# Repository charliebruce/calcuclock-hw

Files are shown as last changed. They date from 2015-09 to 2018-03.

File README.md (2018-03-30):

# calcuclock-hw
PCB and schematic for the calcuclock project. The firmware for this hardware can be found at https://github.com/charliebruce/calcuclock-sw

This PCB can be purchased through OSHPark: https://oshpark.com/shared_projects/vCfoimMo

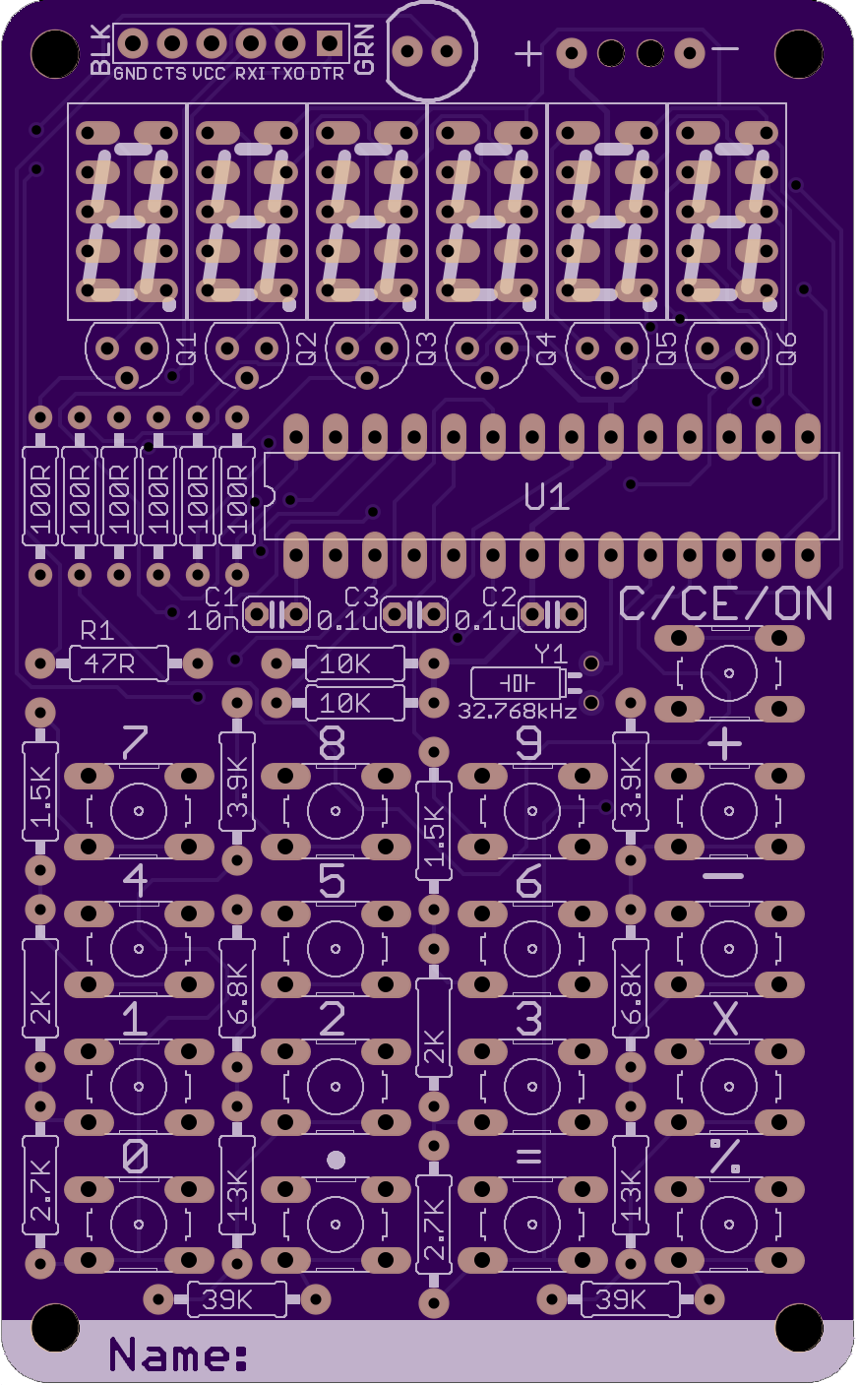
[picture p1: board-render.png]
PCB Render


# License
Released under the CC BY-NC-SA 3.0 license.

For more details see a summary at:
https://creativecommons.org/licenses/by-nc-sa/3.0/ 
and the accompanying legal text:
https://creativecommons.org/licenses/by-nc-sa/3.0/legalcode

Please raise an issue or send me an email if you wish to use this project commercially.

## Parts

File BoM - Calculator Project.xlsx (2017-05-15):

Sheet: Parts
Calculator Project - BOM
Quantity required | 12 |  | VAT Rate | 20.0%
Item | Qty required/kit | OC (Farnell) | Qty required total | Qty (MOQ) | Price/unit | Line Total |  | MOQ | 1 | 5 | 10 | 25 | 50 | 100 | 250 | 500 | 1000 | 3000 | 5000
7-Segment CA (Green) | 6 | 1830007 | 72 | 72 | £0.31 | £22.32 |  | 1 | £0.33 | £0.33 | £0.33 | £0.31 | £0.31 | £0.27 | £0.26 | £0.24 | £0.24 | £0.24 | £0.24
 |  | Colour Options: 1830007 , 1830002 , 1830009 , 1830005 , 1830011.
ATmega328P-PU | 1 | 1715487 | 12 | 12 | £1.64 | £19.68 |  | 1 | £2.81 | £2.81 | £1.64 | £1.64 | £1.64 | £1.34 | £1.33 | £1.33 | £1.33 | £1.33 | £1.33
Switch, SPST | 17 | 9471685 | 204 | 205 | £0.04 | £9.02 |  | 5 |  | £0.09 | £0.09 | £0.09 | £0.08 | £0.04 | £0.04 | £0.04 | £0.04 | £0.04 | £0.04
Capacitor, 10nF | 1 | 1216425 | 12 | 15 | £0.07 | £1.01 |  | 5 |  | £0.07 | £0.07 | £0.07 | £0.06 | £0.04 | £0.04 | £0.03 | £0.03 | £0.03 | £0.03
Capacitor, 0.1uF | 2 | 2309020 | 24 | 24 | £0.02 | £0.55 |  | 1 | £0.03 | £0.03 | £0.02 | £0.02 | £0.02 | £0.02 | £0.02 | £0.02 | £0.01 | £0.01 | £0.01
Crystal, 32.768khz | 1 | 1652573 | 12 | 12 | £0.11 | £1.34 |  | 1 | £0.11 | £0.11 | £0.11 | £0.10 | £0.09 | £0.08 | £0.08 | £0.07 | £0.07 | £0.07 | £0.07
Transistor, PNP | 6 | 1574374 | 72 | 75 | £0.11 | £8.25 |  | 5 |  | £0.14 | £0.14 | £0.11 | £0.11 | £0.07 | £0.07 | £0.07 | £0.04 | £0.04 | £0.04
Header, 6 pin, RA | 1 | 1593430 | 12 | 20 | £0.19 | £3.82 |  | 10 |  |  | £0.19 | £0.19 | £0.13 | £0.08 | £0.08 | £0.06 | £0.05 | £0.05 | £0.05
Battery Container | 1 | Rapid: 18-0124 | 12 | 12 | £0.26 | £3.08 |  | 1 | £0.26 | £0.26 | £0.26 | £0.20 | £0.20 | £0.15 | £0.15 | £0.13 | £0.13 | £0.13 | £0.13
IR TX | 1 | 2290441 | 12 | 12 | £0.08 | £0.97 |  | 1 | £0.09 | £0.09 | £0.08 | £0.08 | £0.08 | £0.07 | £0.07 | £0.06 | £0.06 | £0.06 | £0.06
IR RX?
IR Trans?
Chip socket?
Resistors
100R 5% | 6 | 2329473 | 72 | 80 | £0.01 | £0.88 |  | 10 |  |  | £0.01 | £0.01 | £0.01 | £0.01 | £0.01 | £0.01 | £0.01 | £0.01 | £0.01
47R 5% | 1 | 2329533 | 12 | 20 | £0.01 | £0.26 |  | 10 |  |  | £0.01 | £0.01 | £0.01 | £0.01 | £0.01 | £0.01 | £0.01 | £0.01 | £0.01
10K | 2 | 2329474 | 24 | 30 | £0.01 | £0.39 |  | 10 |  |  | £0.01 | £0.01 | £0.01 | £0.01 | £0.01 | £0.01 | £0.01 | £0.01 | £0.01
1.5K | 2 | 9341323 | 24 | 50 | £0.06 | £2.75 |  | 50 |  |  |  |  | £0.06 | £0.06 | £0.06 | £0.05 | £0.03 | £0.03 | £0.02
2K | 2 | 9341480 | 24 | 50 | £0.03 | £1.35 |  | 50 |  |  |  |  | £0.03 | £0.03 | £0.03 | £0.02 | £0.02 | £0.02 | £0.01
2.7K | 2 | 9341641 | 24 | 50 | £0.06 | £2.75 |  | 50 |  |  |  |  | £0.06 | £0.06 | £0.06 | £0.05 | £0.03 | £0.03 | £0.02
3.9K | 2 | 9341854 | 24 | 50 | £0.06 | £2.75 |  | 50 |  |  |  |  | £0.06 | £0.06 | £0.06 | £0.05 | £0.03 | £0.03 | £0.02
6.8K | 2 | 9342168 | 24 | 50 | £0.06 | £2.75 |  | 50 |  |  |  |  | £0.06 | £0.06 | £0.06 | £0.05 | £0.03 | £0.03 | £0.02
13K | 2 | 9341285 | 24 | 50 | £0.03 | £1.30 |  | 50 |  |  |  |  | £0.03 | £0.03 | £0.03 | £0.02 | £0.02 | £0.02 | £0.01
39K | 2 | 2329932 | 24 | 30 | £0.02 | £0.63 |  | 10 |  |  | £0.02 | £0.02 | £0.02 | £0.01 | £0.01 | £0.01 | £0.01 | £0.01 | £0.01
PCB (90x55mm, dual layer) | 1 |  | 12 | 12 | £1.90 | £22.80 |  | 12
 |  |  |  |  | VAT | £21.73
 |  |  |  |  | Total | £130.39 | (as listed - quote may lower price)
 |  |  |  |  |  | £10.87 | per unit

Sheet: Alt PCB.
Alt PCB services
PCBCart | ENIG | 12day |  |  |  |  | 55.926 | tool
$2.04 | £1.33 |  |  | 50 | £66.30 |  | £122.23 |  | £2.44 | each, qty | 50 | exc ship, qc fail, import
$1.55 | £1.01 |  | for | 100 | £100.75 | exc tooling | £156.68 |  | £1.57 | each, qty | 100
$1.29 | £0.84 |  |  | 200 | £167.70 |  | £223.63 |  | £1.12 | each, qty | 200
$1.22 | £0.79 |  |  | 250 | £198.25 |  | £254.18 |  | £1.02 | each, qty | 250
$0.99 | £0.64 |  |  | 500 | £321.75 |  | £377.68 |  | £0.76 | each, qty | 500
$0.87 | £0.57 |  |  | 1000 | £565.50 |  | £621.43 |  | £0.62 | each, qty | 1000
$0.78 | £0.51 |  |  | 2000 | £1014.00 |  | £1069.93 |  | £0.53 | each, qty | 2000

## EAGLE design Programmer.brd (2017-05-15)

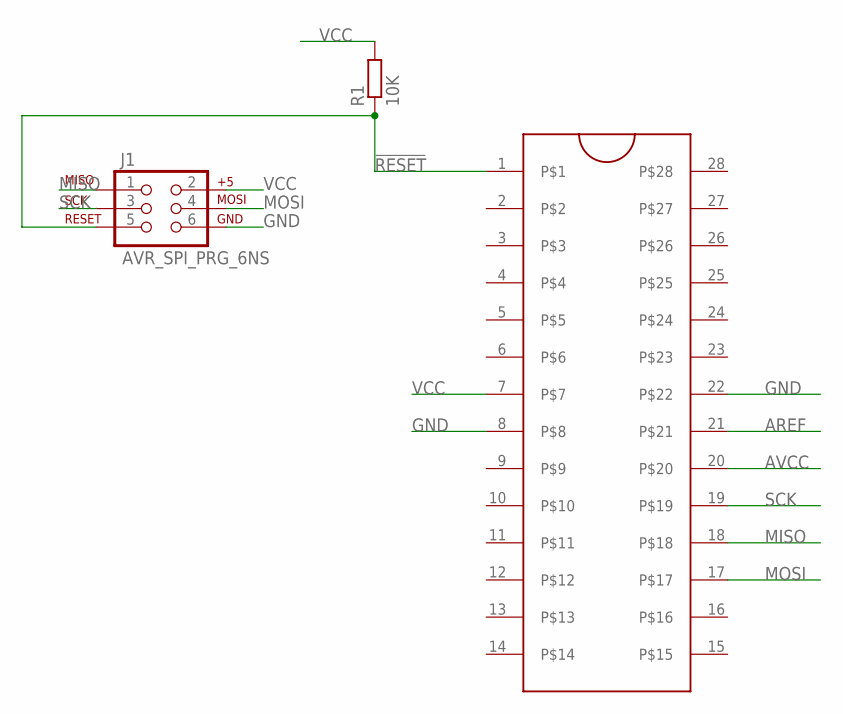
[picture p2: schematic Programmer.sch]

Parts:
J1: AVR_SPI_PRG_6NS; 2X3-NS
R1: 10K; 0207/10
U$1: ZIFSOCKET-28-3ZIFFSOCKET-28-3; DIL28-3-ZIF_SOCKET

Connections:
!RESET!: J1.5, R1.1, U$1.1
AREF: U$1.21
AVCC: U$1.20
GND: J1.6, U$1.8, U$1.22
MISO: J1.1, U$1.18
MOSI: J1.4, U$1.17
SCK: J1.3, U$1.19
VCC: J1.2, R1.2, U$1.7

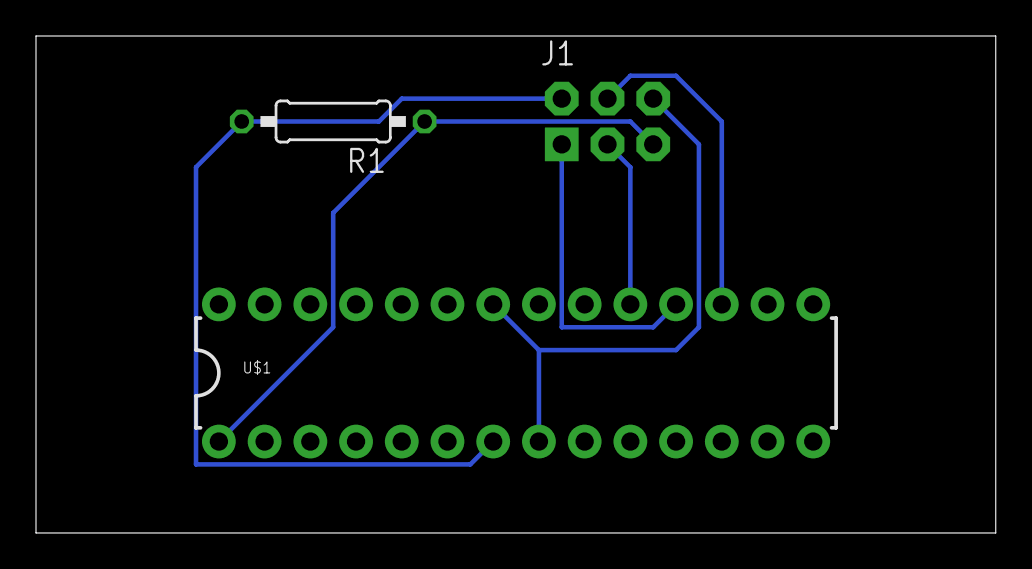
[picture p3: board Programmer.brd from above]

Board: 2 copper layers, 53.3 x 27.6 mm, 3 parts (0 on the bottom side), 6 nets.

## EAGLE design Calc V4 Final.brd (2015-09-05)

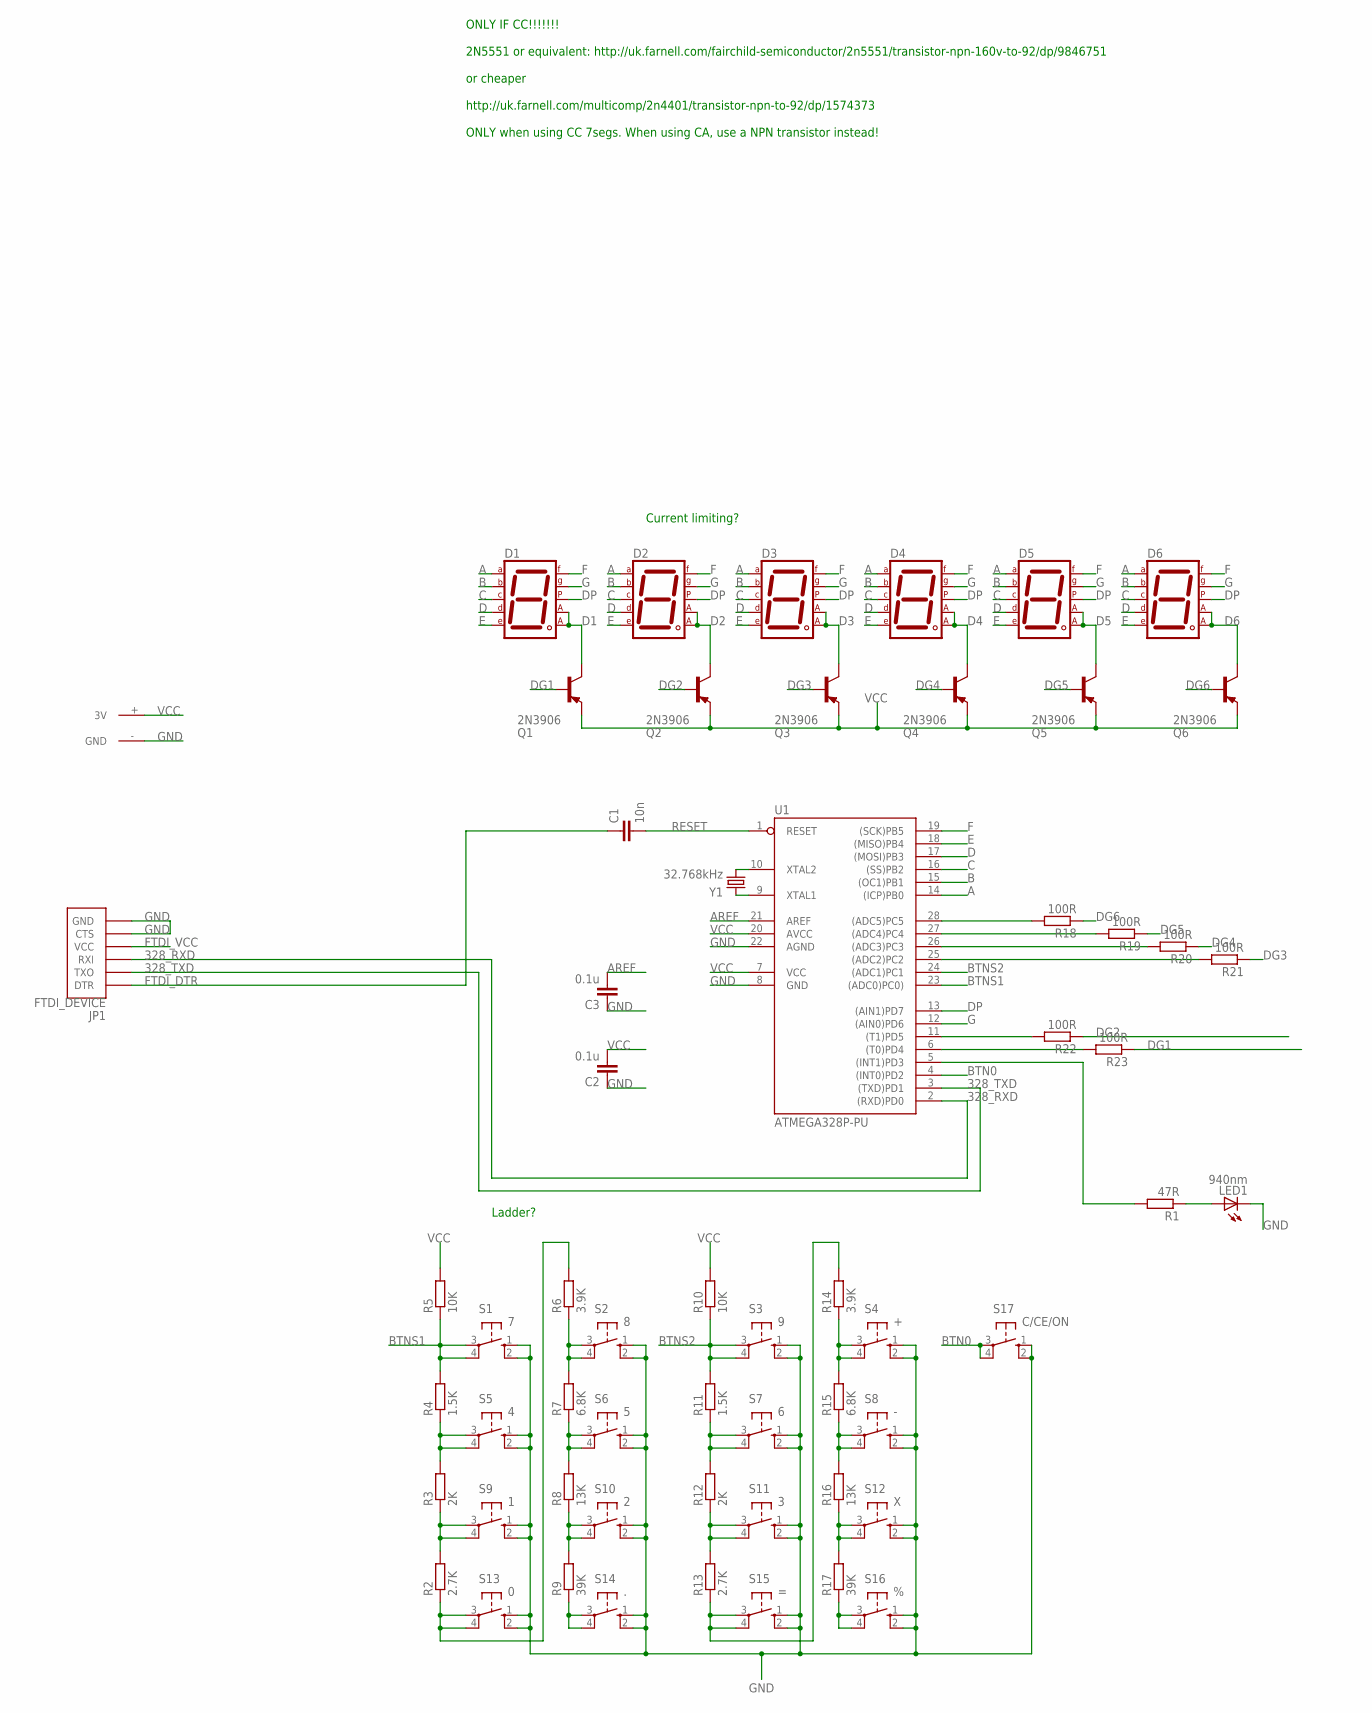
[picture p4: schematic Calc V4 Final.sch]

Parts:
C1: 10n; C025-024X044
C2, C3: 0.1u; C025-024X044
D1, D2, D3, D4, D5, D6: 7SEG-MCA; 7SEG-7
JP1: FTDI_DEVICE; FTDI_DEVICE_SIDE
LED1: 940nm; LED5MM
Q1, Q2, Q3, Q4, Q5, Q6: 2N3906; TO92
R1: 47R; 0207/10
R2, R13: 2.7K; 0207/10
R3, R12: 2K; 0207/10
R4, R11: 1.5K; 0207/10
R5, R10: 10K; 0207/10
R6, R14: 3.9K; 0207/10
R7, R15: 6.8K; 0207/10
R8, R16: 13K; 0207/10
R9, R17: 39K; 0207/10
R18, R19, R20, R21, R22, R23: 100R; 0207/7
S1: 7; B3F-10XX
S2: 8; B3F-10XX; MPN B3F-1000
S3: 9; B3F-10XX; MPN B3F-1000
S4: +; B3F-10XX; MPN B3F-1000
S5: 4; B3F-10XX; MPN B3F-1000
S6: 5; B3F-10XX; MPN B3F-1000
S7: 6; B3F-10XX; MPN B3F-1000
S8: -; B3F-10XX; MPN B3F-1000
S9: 1; B3F-10XX
S10: 2; B3F-10XX; MPN B3F-1000
S11: 3; B3F-10XX; MPN B3F-1000
S12: X; B3F-10XX; MPN B3F-1000
S13: 0; B3F-10XX; MPN B3F-1000
S14: .; B3F-10XX; MPN B3F-1000
S15: =; B3F-10XX; MPN B3F-1000
S16: %; B3F-10XX; MPN B3F-1000
S17: C/CE/ON; B3F-10XX; MPN B3F-1000
U1: ATMEGA328P-PU; DIL28-3
U$1: AAA-BATTERY; AAA-BATTERY-CONTACT
Y1: 32.768kHz; TC26HEZ

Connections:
328_RXD: JP1.P$3 (RXI), U1.2 ((RXD)PD0)
328_TXD: JP1.P$2 (TXO), U1.3 ((TXD)PD1)
A: D1.10 (A), D2.10 (A), D3.10 (A), D4.10 (A), D5.10 (A), D6.10 (A), U1.14 ((ICP)PB0)
AREF: C3.2, U1.21 (AREF)
B: D1.9 (B), D2.9 (B), D3.9 (B), D4.9 (B), D5.9 (B), D6.9 (B), U1.15 ((OC1)PB1)
BTN0: S17.3, S17.4 (P1), U1.4 ((INT0)PD2)
BTNS1: R4.2, R5.1, S1.3, S1.4 (P1), U1.23 ((ADC0)PC0))
BTNS2: R10.1, R11.2, S3.3, S3.4 (P1), U1.24 ((ADC1)PC1)
C: D1.8 (C), D2.8 (C), D3.8 (C), D4.8 (C), D5.8 (C), D6.8 (C), U1.16 ((SS)PB2)
D: D1.5 (D), D2.5 (D), D3.5 (D), D4.5 (D), D5.5 (D), D6.5 (D), U1.17 ((MOSI)PB3)
D1: D1.1 (CA1), D1.6 (CA2), Q1.1 (C)
D2: D2.1 (CA1), D2.6 (CA2), Q2.1 (C)
D3: D3.1 (CA1), D3.6 (CA2), Q3.1 (C)
D4: D4.1 (CA1), D4.6 (CA2), Q4.1 (C)
D5: D5.1 (CA1), D5.6 (CA2), Q5.1 (C)
D6: D6.1 (CA1), D6.6 (CA2), Q6.1 (C)
DG1: Q1.2 (B), R23.1
DG2: Q2.2 (B), R22.1
DG3: Q3.2 (B), R21.1
DG4: Q4.2 (B), R20.1
DG5: Q5.2 (B), R19.1
DG6: Q6.2 (B), R18.1
DP: D1.7 (DP), D2.7 (DP), D3.7 (DP), D4.7 (DP), D5.7 (DP), D6.7 (DP), U1.13 ((AIN1)PD7)
E: D1.4 (E), D2.4 (E), D3.4 (E), D4.4 (E), D5.4 (E), D6.4 (E), U1.18 ((MISO)PB4)
F: D1.2 (F), D2.2 (F), D3.2 (F), D4.2 (F), D5.2 (F), D6.2 (F), U1.19 ((SCK)PB5)
FTDI_DTR: C1.1, JP1.P$1 (DTR)
FTDI_VCC: JP1.P$4 (VCC)
G: D1.3 (G), D2.3 (G), D3.3 (G), D4.3 (G), D5.3 (G), D6.3 (G), U1.12 ((AIN0)PD6)
GND: C2.1, C3.1, JP1.P$5 (CTS), JP1.P$6 (GND), LED1.K (C), S1.1 (S), S1.2 (S1), S2.1 (S), S2.2 (S1), S3.1 (S), S3.2 (S1), S4.1 (S), S4.2 (S1), S5.1 (S), S5.2 (S1), S6.1 (S), S6.2 (S1), S7.1 (S), S7.2 (S1), S8.1 (S), S8.2 (S1), S9.1 (S), S9.2 (S1), S10.1 (S), S10.2 (S1), S11.1 (S), S11.2 (S1), S12.1 (S), S12.2 (S1), S13.1 (S), S13.2 (S1), S14.1 (S), S14.2 (S1), S15.1 (S), S15.2 (S1), S16.1 (S), S16.2 (S1), S17.1 (S), S17.2 (S1), U1.8 (GND), U1.22 (AGND), U$1.- (GND)
unnamed: LED1.A, R1.1
unnamed: R1.2, U1.5 ((INT1)PD3)
unnamed: R2.1, R6.2, S13.3, S13.4 (P1)
unnamed: R2.2, R3.1, S9.3, S9.4 (P1)
unnamed: R3.2, R4.1, S5.3, S5.4 (P1)
unnamed: R6.1, R7.2, S2.3, S2.4 (P1)
unnamed: R9.1, S14.3, S14.4 (P1)
unnamed: R8.1, R9.2, S10.3, S10.4 (P1)
unnamed: R7.1, R8.2, S6.3, S6.4 (P1)
unnamed: R18.2, U1.28 ((ADC5)PC5)
unnamed: R11.1, R12.2, S7.3, S7.4 (P1)
unnamed: R13.1, R14.2, S15.3, S15.4 (P1)
unnamed: R12.1, R13.2, S11.3, S11.4 (P1)
unnamed: R17.1, S16.3, S16.4 (P1)
unnamed: R16.1, R17.2, S12.3, S12.4 (P1)
unnamed: R15.1, R16.2, S8.3, S8.4 (P1)
unnamed: R14.1, R15.2, S4.3, S4.4 (P1)
unnamed: R19.2, U1.27 ((ADC4)PC4)
unnamed: R20.2, U1.26 ((ADC3)PC3)
unnamed: R21.2, U1.25 ((ADC2)PC2)
unnamed: R22.2, U1.11 ((T1)PD5)
unnamed: R23.2, U1.6 ((T0)PD4)
RESET: C1.2, U1.1 (RESET)
VCC: C2.2, Q1.3 (E), Q2.3 (E), Q3.3 (E), Q4.3 (E), Q5.3 (E), Q6.3 (E), R5.2, R10.2, U1.7 (VCC), U1.20 (AVCC), U$1.+ (3V)
XTAL_N: U1.9 (XTAL1), Y1.2
XTAL_P: U1.10 (XTAL2), Y1.1

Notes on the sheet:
Ladder?
Current limiting?
ONLY IF CC!!!!!!! 2N5551 or equivalent: http://uk.farnell.com/fairchild-semiconductor/2n5551/transistor-npn-160v-to-92/dp/9846751 or cheaper http://uk.farnell.com/multicomp/2n4401/transistor-npn-to-92/dp/1574373 ONLY when using CC 7segs. When using CA, use a NPN transistor instead!

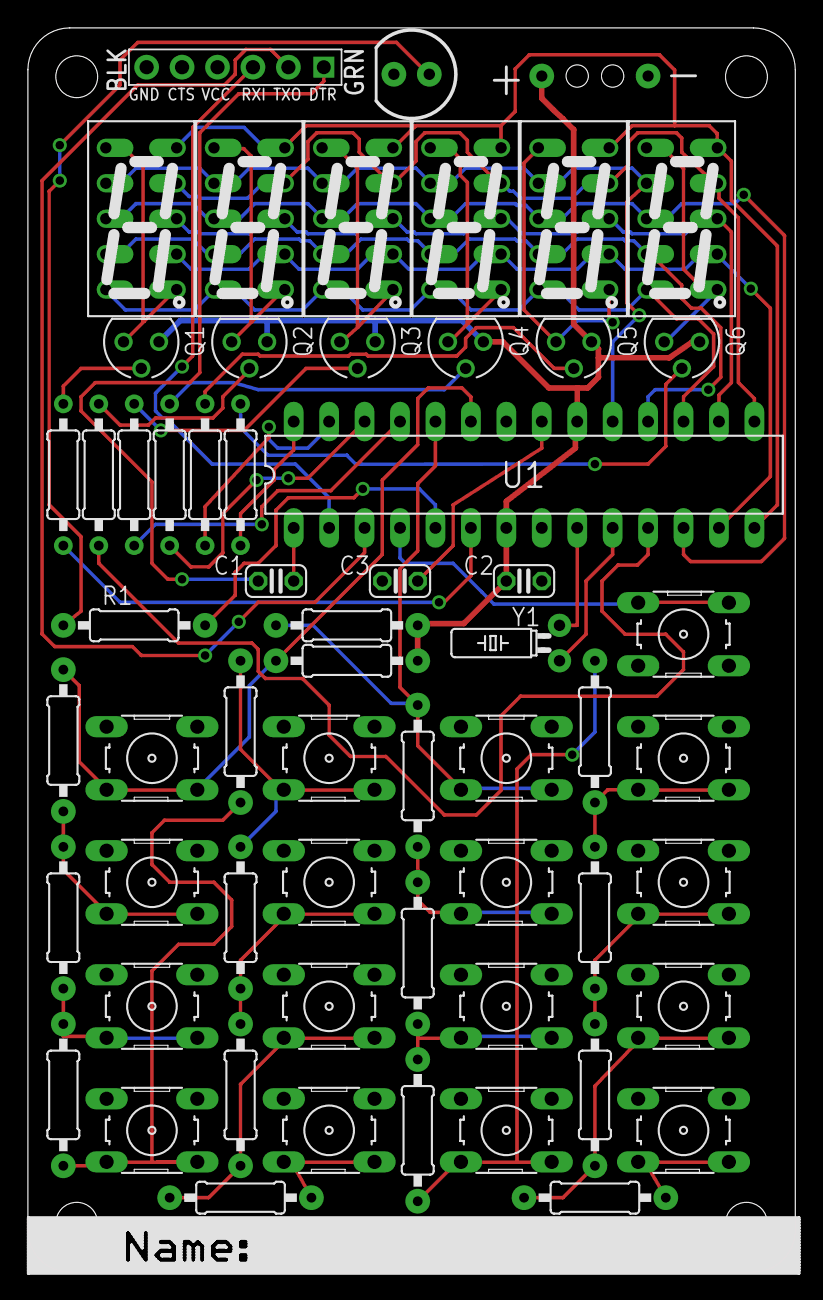
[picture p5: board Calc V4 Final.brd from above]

Board: 2 copper layers, 55.0 x 89.2 mm, 60 parts (0 on the bottom side), 54 nets.

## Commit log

2015-09-05 Initial commit of calcuclock PCB design.
    [Calc V4 Final.brd, Calc V4 Final.sch]
2015-09-05 Add assembly guide.
2017-05-15 Add board render
2017-05-15 Add BoM
    [BoM - Calculator Project.xlsx]
2017-05-15 Add a programming tool board, allows chips to be programmed using AVRISP and a ZIF socket or similar.
    [Programmer.brd, Programmer.sch]

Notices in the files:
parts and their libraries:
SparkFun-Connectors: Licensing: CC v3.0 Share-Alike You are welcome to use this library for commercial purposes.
